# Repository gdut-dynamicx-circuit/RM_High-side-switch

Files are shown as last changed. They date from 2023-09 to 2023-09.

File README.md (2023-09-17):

# RM_High-side switch

&nbsp;&nbsp;&nbsp;&nbsp;

[English](./README.md)/中文

***

### 简介

&nbsp;&nbsp;&nbsp;&nbsp;本项目的开发目的是为了实现了电位控制电流。本项目基于lm5060芯片，实现了控制大电流开关的功能。
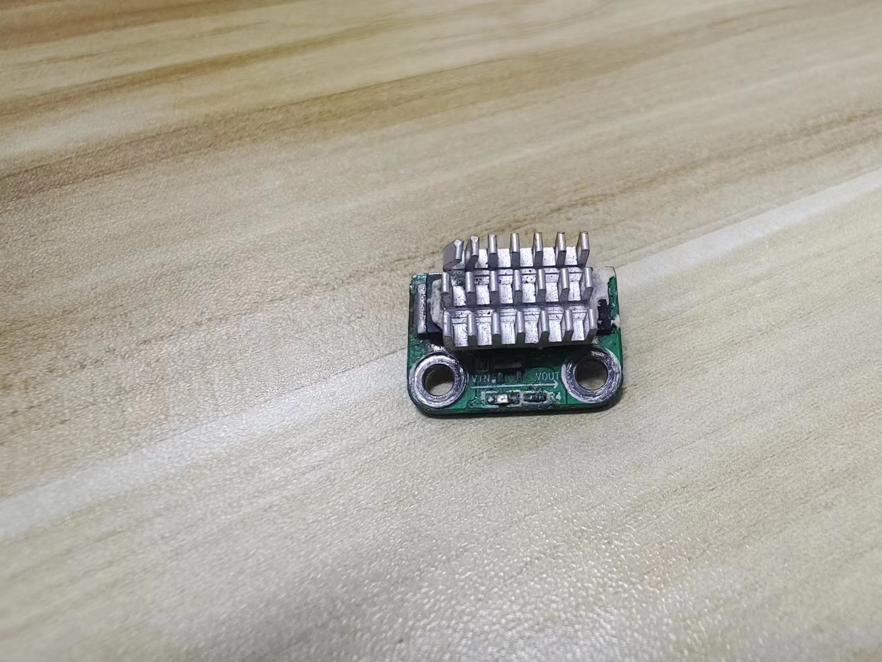
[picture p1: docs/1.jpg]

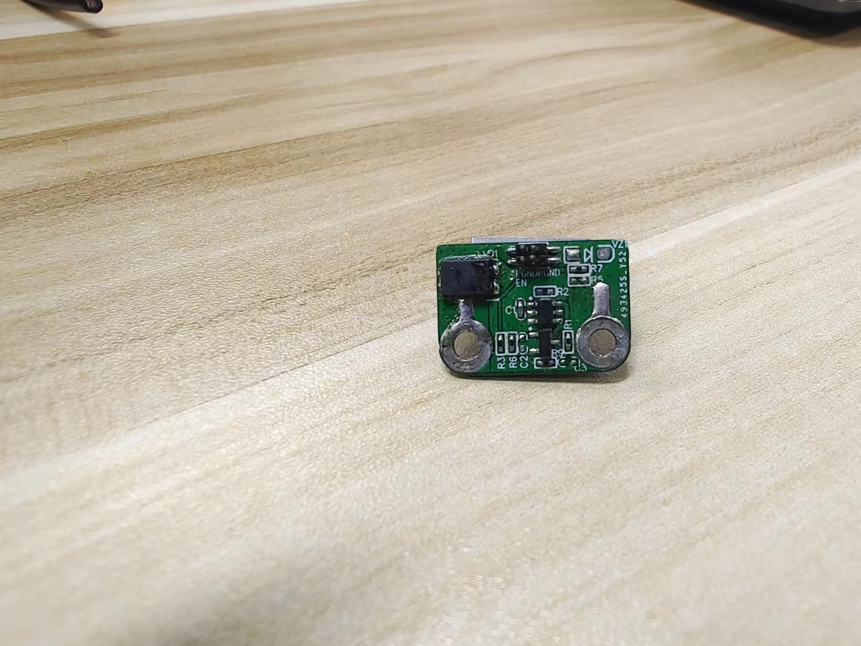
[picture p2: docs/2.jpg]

***

### 开发工具

+ EDA工具：KiCAD 7.0 

***

### 目录结构

+ circuit：基于KiCAD的原理图及PCB设计

+ docs：README相关的图片及文档

**注意：生产制造相关的Gerber、BOM、POS文件及程序固件均在仓库的Release中发布**

***

### 电路设计

#### 原理图设计要点

&nbsp;&nbsp;&nbsp;&nbsp;高侧开关的设计：通过三极管的共射放大电路，实现电位控制Nmos管的导通。在lm5060后面还接入一个可以放电源正负极反接作用的电路。在lm5060的GATE的引脚处串联了一个电阻再反并一个二极管和实现电源快开慢关的作用。

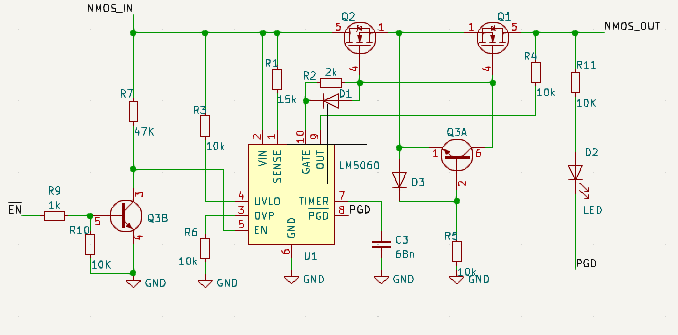
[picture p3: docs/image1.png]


#### PCB布局布线要点

1. VIN旁路电容器靠近引脚VIN.
2. 计时器电容器靠近针脚TIMER.
3. MOS管处pcb打孔确保正反面导通

***

**组织：DynamicX <br>
维护人：陈晓根, 2383725658@qq.com**

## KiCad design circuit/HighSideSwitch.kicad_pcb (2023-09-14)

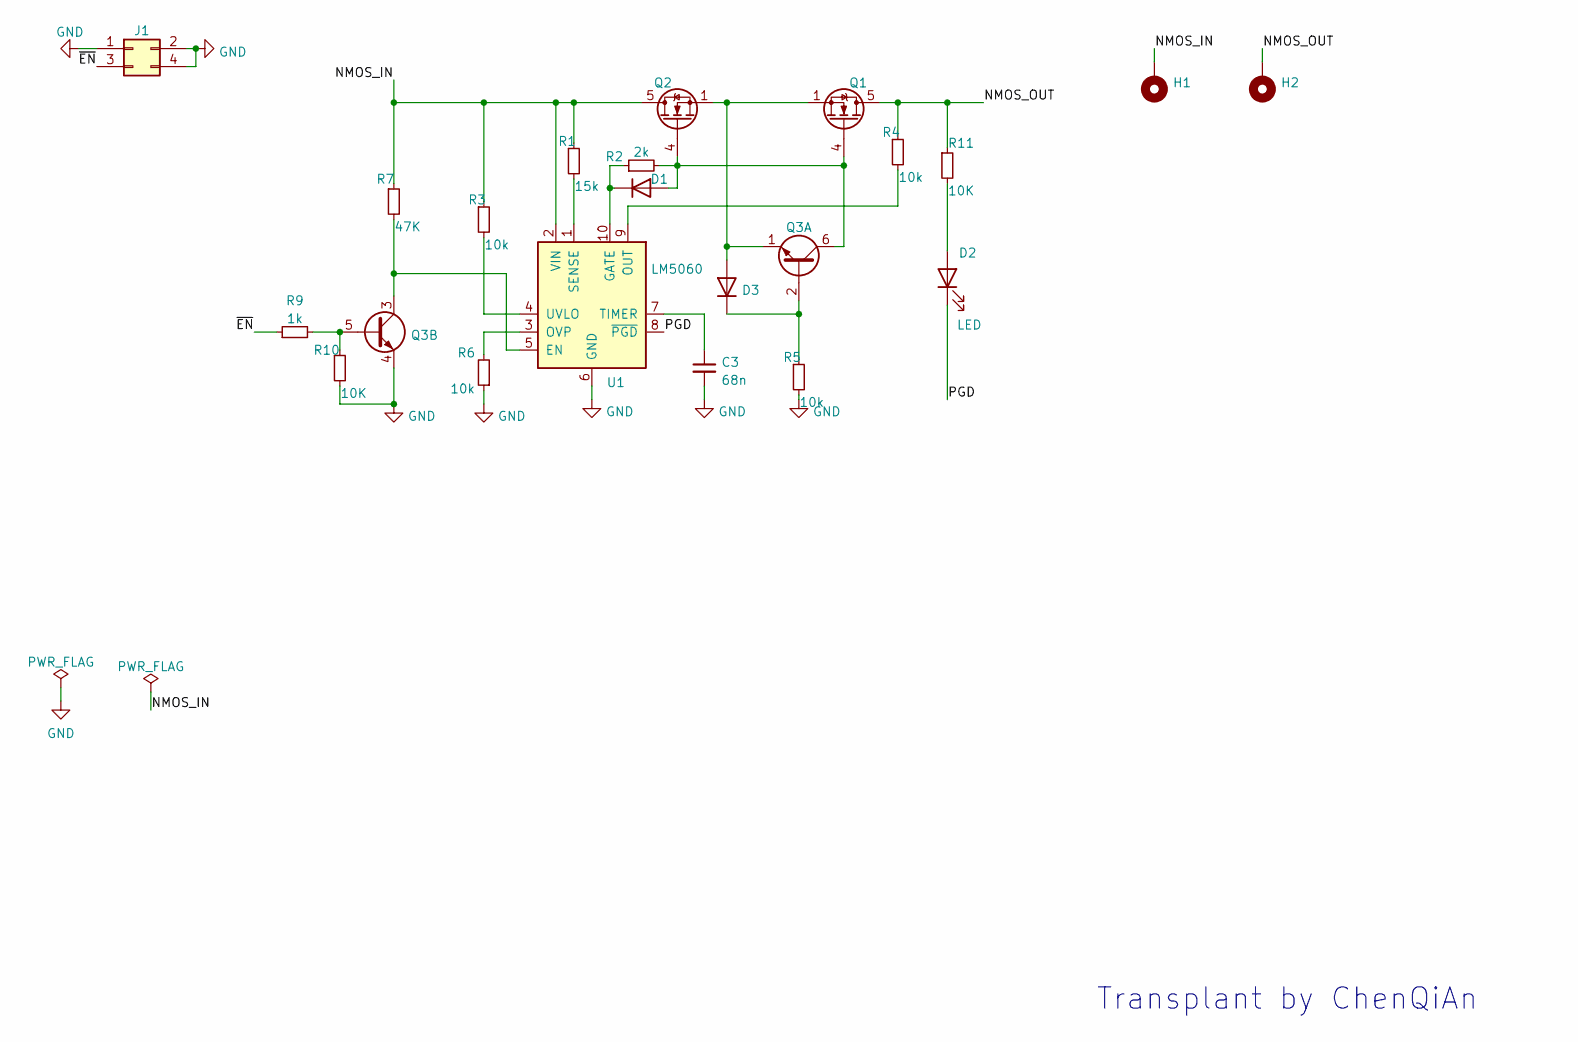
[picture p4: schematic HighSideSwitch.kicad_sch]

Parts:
C3: 68n; C_0402_1005Metric
D1, D3: 1N4001; D_SOD-323
D2: LED; LED_0603_1608Metric
H1, H2: MountingHole_Pad; MountingHole_3.2mm_M3_Pad_Via
J1: Conn_02x02_Odd_Even; PinHeader_2x02_P1.27mm_Vertical_SMD
Q1, Q2: CSD18540Q5B; TDSON-8-1
Q3: Q_Dual_NPN_NPN_E1B1C2E2B2C1; SOT-363_SC-70-6
R1: 15k; R_0402_1005Metric
R2: 2k; R_0402_1005Metric
R3, R4, R5, R6: 10k; R_0402_1005Metric
R7: 47K; R_0402_1005Metric
R9: 1k; R_0402_1005Metric
R10, R11: 10K; R_0402_1005Metric
U1: LM5060; MSOP-10_3x3mm_P0.5mm

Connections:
/NMOS_IN: H1.1, Q2.5 (D), R1.1, R3.1, R7.1, U1.2 (VIN)
/NMOS_OUT: H2.1, Q1.5 (D), R4.1, R11.1
/PGD: D2.1 (K), U1.8 (~PGD)
/~EN: J1.3, R9.1
GND: C3.2, J1.1, J1.2, J1.4, Q3.4 (E2), R5.2, R6.1, R10.2, U1.6 (GND)
unnamed: C3.1, U1.7 (TIMER)
unnamed: D1.1 (K), R2.1, U1.10 (GATE)
unnamed: D1.2 (A), Q1.4 (G), Q2.4 (G), Q3.6 (C1), R2.2
unnamed: D2.2 (A), R11.2
unnamed: D3.1 (K), Q3.2 (B1), R5.1
unnamed: D3.2 (A), Q1.1 (S), Q1.2 (S), Q1.3 (S), Q2.1 (S), Q2.2 (S), Q2.3 (S), Q3.1 (E1)
unnamed: Q3.3 (C2), R7.2, U1.5 (EN)
unnamed: Q3.5 (B2), R9.2, R10.1
unnamed: R1.2, U1.1 (SENSE)
unnamed: R3.2, U1.4 (UVLO)
unnamed: R4.2, U1.9 (OUT)
unnamed: R6.2, U1.3 (OVP)

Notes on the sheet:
Transplant by ChenQiAn

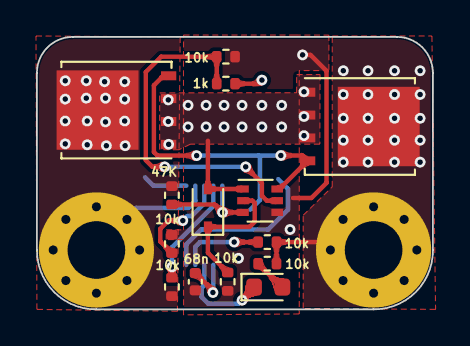
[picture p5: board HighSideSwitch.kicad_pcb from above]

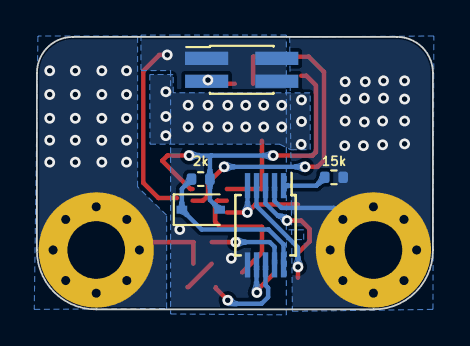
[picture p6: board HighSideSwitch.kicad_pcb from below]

Board: 2 copper layers, 22.0 x 15.1 mm, 21 parts (5 on the bottom side), 17 nets.

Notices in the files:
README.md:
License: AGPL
